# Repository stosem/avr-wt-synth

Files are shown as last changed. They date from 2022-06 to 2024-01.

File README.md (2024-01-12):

# Info

Eurorack Wavetable-based VCO. Atari Glitch. DIY

## Atari Glitch Synthesizer
This is the VCO (voltage controlled oscillator) audio synthesizer module for the Eurorack Modular systems. 
It's based on the Wavetable and FM synthesis using Arduino Mozzi library. 
See the basic circuit diagram in the `cad` folder.

## Interface

We have 4 main potentiometers B100K in order to set Sytentesizer's parameters:
* Wavetable - choose a wavetable 
* Modulation - set modulation depth 
* Obertone - set amount of overtone sound 
* Glitch - FM operator amount 

The same parameters can be set using CV inputs on 3.5mm Jacks. There are several additional CV inputs: 
* Trigger - main gate signal (1-5V) to initiate (trigger) a note 
* 1V/OCT - one volt per octave - the pitch of the note to play 

There is one audio output, also on 3.5mm jack socket: 
* OUT - audio out 

We have also one Switch to choose the Synthesizer mode between two possible modes: 
* Standard FM/Wavetable synth. You can set any parameters using potentiometers or CV signals (higher priority) 
* Random synthesizer. In this mode, all parameters are generated randomly on each step (trigger). Potentiometers now are limiting the maximum possible value of randomly generated values. Set a potentiometer to 0 (zero) if you want to unlimit a random value range. 

## Board
The Synthesizer consists of two boards. 
1. The Interface board, where all potentiometers and 3.5mm jack ports are located
2. The main logic board

All schemes are in the cad directory.

## Demo

Sound demo:

https://www.youtube.com/watch?v=aY03wGdam5E

# User manual

## Switch

* Random On/Off random feature.

If random feature is On, the new sound will be generated at each trigger CV signal

## Knobs

You can switch any knob to 0 value by turning it clockwise till the click.

| Parameter name | Description | Normal mode | Random mode |
| --- | --- | --- | --- |
| WAVE | WaveTable select | Select WaveTable from 0 to max available (MAX\_WT) | Limit Random Wavetable. 0=ALL |
| OBER | Obertone freq | Set Obertone Freq | Limit Obertone Freq. 0=ALL |
| GLITCH | FM intensity | Set FM intensity | Limit FM intensity. 0=ALL |
| MOD | Modulation Rate | Set wah-wah effect | Limit Mod ratio. 0=ALL |

## CVs

CVs have higher priority than knobs

| Parameter name | Description | Normal mode | Random mode |
| --- | --- | --- | --- |
| TRIG | Trigger CV | Make a sound | Generate a random sound |
| V/OCT | Pitch CV | Set pitch (will be quantized to a note) | Set pitch. 0 or no signal = Random pitch |
| GLCH | FM intensity | Set FM intensity | - |
| OBER | Obertone freq | Set obertone freq | - |
| MOD | Modulation Rate | Set wah-wah effect | - |

## Notes

Current range is 5 octaves from C1 to C6

## WaveTables

1. HSN - Half Sinus
2. SIN - Full Sinus
3. SQR - Square
4. SAW - Sawtooth
5. TRI - Triangle

# Developers

## Tips

* Do not use digital pins 11,12,13 if you want to use MOSI/MISO Atmega programmer (especially with capacitors)
* Do not use digital pins 9,10. They are used by Mozzi sound generator
* Change OpIntensityMod WaveTable if you want to get creazy sound
* Use DEBUG\_INPUT to check CVs and knobs. But it's not a good idea to use the Serial messages with Mozzi. Don't forget to undefine debugs.

## Known bugs

* AutoMap doesn't work till it get the maximum value from CV/Knob. It returns always maximum. We can't replace it with map() because it's very slow. Fixed by pushing max value first.
* map() and AutoMap works not so good on the minimum value. For example 0 and 15 - are the same values for it. Therefore C0 and C#0 - are the same notes. Fixed by if-then-hack.

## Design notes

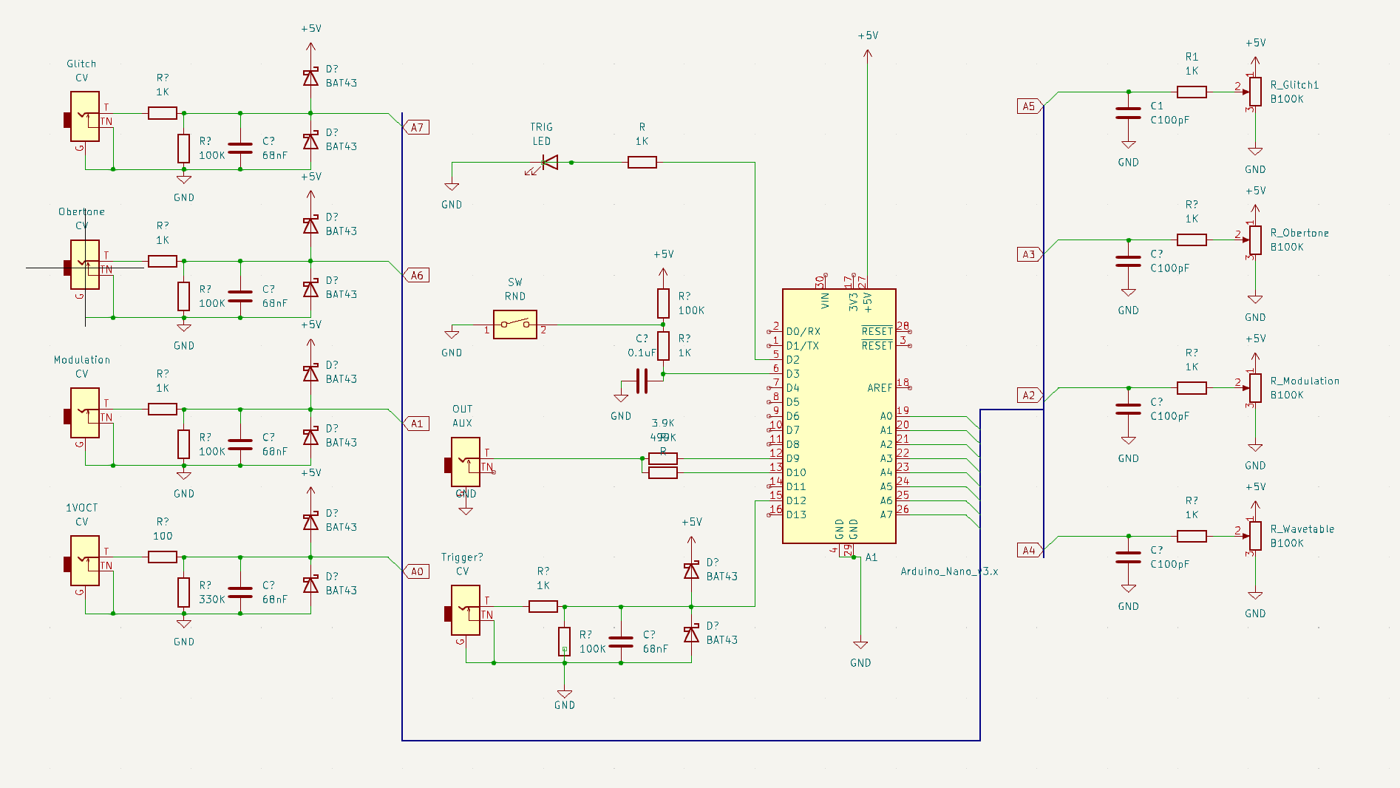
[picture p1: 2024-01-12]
cad/Scheme.png

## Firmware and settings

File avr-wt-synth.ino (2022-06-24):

/*
 * ATARI GLITCH Eurorack module by Alex Bohrium
 * firmware v1.0
 */

#include <MozziGuts.h>
#include <Oscil.h> // oscillator 

#include "tables/halfsin2048_int8.h" // table for Oscils to play
#include <tables/sin2048_int8.h>
#include <tables/square_no_alias_2048_int8.h>
#include <tables/saw2048_int8.h>
#include <tables/triangle2048_int8.h>

#include <Smooth.h>
#include <AutoMap.h> // maps unpredictable inputs to a range

#include <mozzi_rand.h>

/* constants
 *  
 */

// uncomment to debug messages via serial cable
//#define DEBUG_INPUT
//#define DEBUG
#define DEFAULT_BRIGHT     5        // brightness, harmonics
#define DEFAULT_VOL        10       // volume

// constants for mappings
 
// desired carrier frequency (pitch)
#define MIN_CARRIER_FREQ  32.70
#define MAX_CARRIER_FREQ  1046.50
#define DEFAULT_FREQ      220  // if no 1V/Oct signal

// Obertone freq
#define MIN_OBER_FREQ          1
#define MAX_OBER_FREQ          100

// desired intensity max and min, (glitch amount)
#define MAX_INTENSITY     700
#define MIN_INTENSITY     1

// desired mod speed max and min, (fm mod rate)
#define MAX_MOD_SPEED     10000
#define MIN_MOD_SPEED     1

// number of wavetables
#define MAX_WT            5

/* mappings
 *
 */
#define ANALOG_ZERO       10   // minimum treshold to detect a zero/non-zero state (0-1023)

// knobs and CVs maps
AutoMap kMapCarrierFreq( 0, 1023, MIN_CARRIER_FREQ, MAX_CARRIER_FREQ );
AutoMap kMapIntensity( 0, 1023, MIN_INTENSITY, MAX_INTENSITY );
AutoMap kMapModSpeed( 0, 1023, MIN_MOD_SPEED, MAX_MOD_SPEED );
AutoMap kMapOberFreq( 0, 1023, MIN_OBER_FREQ, MAX_OBER_FREQ );
AutoMap kMapWT( 0, 1023, 1, MAX_WT );
// note maps
AutoMap tone_index_map( 0, 1023, 0, 59 );

// notes from C1 to C6
float note_freq[61] = {65.41,   69.30,   73.42,   77.78,   82.41,   87.31,   92.50,   98.00,   103.83,  110.00,  116.54,  123.47,
                       130.81,  138.59,  147.83,  155.56,  164.81,  174.61,  185.00,  196.00,  207.65,  220.00,  233.08,  246.94,
                       261.63,  277.18,  293.66,  311.13,  329.63,  349.23,  369.99,  392.00,  415.30,  440.00,  466.16,  493.88,
                       523.25,  554.37,  587.33,  622.25,  659.25,  698.46,  739.99,  783.99,  830.61,  880.00,  932.33,  987.77,
                       1046.50, 1108.73, 1174.66, 1244.51, 1318.51, 1396.91, 1479.98, 1567.98, 1661.22, 1720.00, 1864.60, 1975.50, 2093.00};

// Hadrware depending configuration
// digital i/o
#define DEBUG_LED   13 // LED for internal debug
#define TRIGGER_LED 2  // Trigger Led will blink when the gate is open
#define RND_SWITCH  3  // Switch RND/Normal
#define TRIGGER_PIN 12 // Sound trigger pin
// analog input
// knobs
#define OBER_KNOB   A3  // Obertone knob
#define MOD_KNOB    A2  // Modulation rate knob
#define WT_KNOB     A4  // Wavetable select knob
#define GLITCH_KNOB A5  // Glitch knob
// CVs
#define MOD_CV      A1  // Modulation rate CV     (wah-wah effect)
#define PITCH_CV    A0  // 1/OCT CV               (base carrier freq / pitch)
#define OBER_CV     A6  // Ober CV                (obertone freq / pitch)
#define GLITCH_CV   A7  // Glitch amount CV       (FM intensity / glitch)


/* variables (may be changed during the work)
 *  
 */

Oscil<2048, AUDIO_RATE>   aOpCarrier;
Oscil<2048, AUDIO_RATE>   aOpModulator;
Oscil<2048, CONTROL_RATE> cOpIntensityMod;

long fm_intensity;                  // carriers control info from updateControl to updateAudio

// smoothing for intensity to remove clicks on transitions
float smoothness = 0.95f;

Smooth <long> aSmoothIntensity(smoothness);

// trigger on flag (change me on trigger button or CV)
bool isTrigger = false;

// regenerate flag
bool isNeedRegenerate = false;

// mode (rnd-generated or manually set)
bool isRND = true;

// define wavetable types
typedef enum WT {
  HSN = 1,
  SIN = 2,
  SQR = 3,
  SAW = 4,
  TRI = 5,
  RND = 6,
} WT;

// define FM-based sound variables
typedef struct tFM {
  int   wt;         // wavetable number
  float carr_freq;  // carrier freq
  int   ober_freq;  // obertone freq
  int   vol;        // volume
  int   fmi;        // FM intensity
  int   bright;     // Brightness (harmonics)
  float mod;   // Modulation rate
} tFM;

// use this function only on debug! it has delay!
void blink_led( int led ) {
      digitalWrite(led, HIGH);
      delay( 100 );
      digitalWrite(led, LOW);
      delay( 100 );
}

// init
void setup(){
#ifdef DEBUG
  Serial.begin(115200); // set up the Serial output
#endif
  // define pins
  pinMode(DEBUG_LED, OUTPUT);
  pinMode(TRIGGER_LED, OUTPUT);
  pinMode(TRIGGER_PIN, INPUT);       // trigger cv
  pinMode(RND_SWITCH, INPUT_PULLUP); // Switch connected to GND    
  blink_led( DEBUG_LED );
  blink_led( TRIGGER_LED );

  randSeed();
  blink_led( DEBUG_LED );
  blink_led( TRIGGER_LED );
  
  startMozzi();
  blink_led( DEBUG_LED );
  blink_led( TRIGGER_LED );
  
#ifdef DEBUG
  Serial.print("Setup finish\n\r");
#endif
}

// update Osc values
void mySetOsc(tFM fmSnd) {
#ifdef DEBUG
  Serial.print("SetOSC:\tWT=");
  Serial.print(fmSnd.wt);
  Serial.print("\tCARR_FREQ=");
  Serial.print(fmSnd.carr_freq);
  Serial.print("\tOBER_FREQ=");
  Serial.print(fmSnd.ober_freq);
  Serial.print("\tVOL=");
  Serial.print(fmSnd.vol);
  Serial.print("\tGLCH=");
  Serial.print(fmSnd.fmi);
  Serial.print("\tBRIGHT=");
  Serial.print(fmSnd.bright);
  Serial.print("\tMOD=");
  Serial.print(fmSnd.mod);
  Serial.print(".\n\r");
#endif
  // set wavetable
  switch ( fmSnd.wt ) {
    case HSN:
      aOpCarrier.setTable(      HALFSIN2048_DATA );
      aOpModulator.setTable(    HALFSIN2048_DATA );
      cOpIntensityMod.setTable( HALFSIN2048_DATA );
    break;
    case SIN:
      aOpCarrier.setTable(      SIN2048_DATA );
      aOpModulator.setTable(    SIN2048_DATA );
      cOpIntensityMod.setTable( SIN2048_DATA );
    break;
    case SQR:
      aOpCarrier.setTable(      SQUARE_NO_ALIAS_2048_DATA );
      aOpModulator.setTable(    SQUARE_NO_ALIAS_2048_DATA );
      cOpIntensityMod.setTable( SIN2048_DATA );
      fmSnd.vol = 5;            // reduce volume for this wave
    break;
    case SAW:
      aOpCarrier.setTable(      SAW2048_DATA );
      aOpModulator.setTable(    SAW2048_DATA );
      cOpIntensityMod.setTable( SIN2048_DATA );
    break;
    case TRI:
      aOpCarrier.setTable(      TRIANGLE2048_DATA );
      aOpModulator.setTable(    TRIANGLE2048_DATA );
      cOpIntensityMod.setTable( SIN2048_DATA );
    break;
  }
  //calculate the modulation frequency to stay in ratio
  int mod_freq = fmSnd.carr_freq * fmSnd.ober_freq * fmSnd.bright;
  // calculate the fm_intensity
  fm_intensity = ((long)fmSnd.fmi * fmSnd.vol * (cOpIntensityMod.next()+128))>>8; // shift back to range after 8 bit multiply
  // set the FM oscillator frequencies
  aOpCarrier.setFreq( fmSnd.carr_freq ); 
  aOpModulator.setFreq( mod_freq );
  cOpIntensityMod.setFreq( fmSnd.mod );
}


// Mozzi Update Controls
void updateControl(){

  // digital read
  isTrigger = (digitalRead( TRIGGER_PIN ) == HIGH)?true:false; // trigger pin connected to an external +5V signal
  isRND = (digitalRead( RND_SWITCH ) == LOW)?true:false;       // rnd switch connected to the GND

#ifdef DEBUG_INPUT
  Serial.print("UpdateControl.Read:\tisTrigger=");
  Serial.print(isTrigger);
  Serial.print("\tisRND=");
  Serial.print(isRND);
  Serial.print("\n\r");
#endif
  
  // set trigger led
  if ( isTrigger ) {
    digitalWrite(TRIGGER_LED, HIGH);
  } else {
    digitalWrite(TRIGGER_LED, LOW);
    // need regenerate on the next trigger comming
    if ( isRND && !isNeedRegenerate ) { 
      isNeedRegenerate = true ;
    };
    // we don't want do anything without a trigger
    return;
  }
  
  // analog read
  // knobs
  int wtKnobVal   = mozziAnalogRead( WT_KNOB );      // read wavetable knob        value is 0-1023
  int modKnobVal  = mozziAnalogRead( MOD_KNOB );     // read modulation rate knob  value is 0-1023
  int oberKnobVal = mozziAnalogRead( OBER_KNOB );    // read obertone knob         value is 0-1023
  int fmiKnobVal  = mozziAnalogRead( GLITCH_KNOB );  // read glitch knob           value is 0-1023
  // CVs
  int carrCVVal   = mozziAnalogRead( PITCH_CV );     // read 1V/OCT pitch          value is 0-1023
  int modCVVal    = mozziAnalogRead( MOD_CV );       // read modulation rate CV    value is 0-1023
  int oberCVVal   = mozziAnalogRead( OBER_CV );      // read obertone CV           value is 0-1023
  int fmiCVVal    = mozziAnalogRead( GLITCH_CV );    // read glitch CV             value is 0-1023

  tFM fmSnd; // sound configuration instance
  // AutoMap has an issue: it return wrong value till it doesn't recive the maximum.
  fmSnd.wt=kMapWT( 1023 );
  fmSnd.carr_freq=kMapCarrierFreq( 1023 );
  fmSnd.ober_freq=kMapOberFreq( 1023 );
  fmSnd.vol=DEFAULT_VOL;
  fmSnd.fmi=kMapIntensity( 1023 );
  fmSnd.bright=DEFAULT_BRIGHT;
  fmSnd.mod=kMapModSpeed( 1023 );
  byte noteNum=tone_index_map( 1023 );
      
#ifdef DEBUG_INPUT
  Serial.print("\tWTknob=");
  Serial.print(wtKnobVal);
  Serial.print("\tMODknob=");
  Serial.print(modKnobVal);
  Serial.print("\toOBERknob=");
  Serial.print(oberKnobVal);
  Serial.print("\tGLCHknob=");
  Serial.print(fmiKnobVal);
  Serial.print("\tCARRcv=");
  Serial.print(carrCVVal);
  Serial.print("\tMODcv=");
  Serial.print(modCVVal);
  Serial.print("\tOBERcv=");
  Serial.print(oberCVVal);
  Serial.print("\tGLCHcv=");
  Serial.print(fmiCVVal);
  Serial.print(".\n\r");
#endif

  if ( isRND ) {
  // this is RANDOM mode
    // do we need to generate a new sound? (only on a new trigger)
    if ( isNeedRegenerate ) {
       // set WT limited by WT Knob (if > 0)
       int iMaxWT        = ( wtKnobVal > ANALOG_ZERO )?kMapWT( wtKnobVal ):MAX_WT;  // limit WT range by WT knob (if > 0)
       fmSnd.wt          = rand((int)1,(int)iMaxWT+1);
       // set pitch = CV if it's exists, or RND if no 1V/OCT signal
       fmSnd.carr_freq   = ( carrCVVal > ANALOG_ZERO )?kMapCarrierFreq( carrCVVal ):rand((int)MIN_CARRIER_FREQ,(int)MAX_CARRIER_FREQ+1); // starting not from minimum to skip sub freq
       // set obertone
       int iMaxOber      = ( oberKnobVal > ANALOG_ZERO )?kMapOberFreq( oberKnobVal ):MAX_OBER_FREQ; // limit Obertone Freq by Ober Knob (if > 0)
       fmSnd.ober_freq   = rand((int)MIN_OBER_FREQ,(int)iMaxOber+1);
       // set volume
       fmSnd.vol         = DEFAULT_VOL;
       // set glitch
       int iMaxIntensity = ( fmiKnobVal > ANALOG_ZERO )?kMapIntensity( fmiKnobVal ):MAX_INTENSITY; // limit intensity by Glitch Knob (if > 0)
       fmSnd.fmi         = rand((int)MIN_INTENSITY,(int)iMaxIntensity+1);
       // set modulation rate
       int iMaxMod       = ( modKnobVal > ANALOG_ZERO )?kMapModSpeed( modKnobVal ):MAX_MOD_SPEED; // limit intensity by Glitch Knob (if > 0)
       if ( iMaxMod < MIN_MOD_SPEED ) { iMaxMod = MIN_MOD_SPEED; };
       fmSnd.mod         = (float)rand((int)MIN_MOD_SPEED,(int)iMaxMod-MIN_MOD_SPEED+1)/1000;
       // set brightness
       fmSnd.bright      = DEFAULT_BRIGHT; // rand((int)1,(int)32);
       mySetOsc( fmSnd );
       // regeniration is done
       isNeedRegenerate = false;

#ifdef DEBUG
  Serial.print("UpdateControl.RNDGen:\tCARR_FREQ=");
  Serial.print(fmSnd.carr_freq);
  Serial.print("\tlimitWT=");
  Serial.print(iMaxWT);
  Serial.print("\tlimitOBER=");
  Serial.print(iMaxOber);
  Serial.print("\tlimitCLCH=");
  Serial.print(iMaxIntensity);
  Serial.print("\tlimitMOD=");
  Serial.print(iMaxMod);
  Serial.print(".\n\r");
#endif
    }
    return; // end of RND mode
      
  } else {
  // this is NORMAL mode

    // define FM
    fmSnd.wt = kMapWT( wtKnobVal );
    fmSnd.vol = DEFAULT_VOL; // constant volume
    // set pitch
    // fmSnd.carr_freq = kMapCarrierFreq( carrCVVal ); // raw freq mapping
    noteNum = tone_index_map( carrCVVal )+1;
    // hack: map() detect 0 and 15 as the same value. It returns 0.
    if ( carrCVVal <= 10 ) { noteNum = 0; };
    if (( carrCVVal > 10 ) && ( carrCVVal < 30 )) { noteNum = 1; };
    fmSnd.carr_freq = (float)note_freq[ noteNum ]; // quantized notes
#ifdef DEBUG
  Serial.print("\tnoteNum=");
  Serial.print(noteNum);
  Serial.print(".\n\r");
#endif
    // set obertone freq
    fmSnd.ober_freq = ( oberCVVal > ANALOG_ZERO )?kMapOberFreq( oberCVVal ):kMapOberFreq( oberKnobVal );
    // set FM intensity (glitch)
    fmSnd.fmi       = ( fmiCVVal > ANALOG_ZERO )?kMapIntensity( fmiCVVal ):kMapIntensity( fmiKnobVal );
    // set modulation rate
    fmSnd.mod       = ( modCVVal > ANALOG_ZERO )?(float)kMapModSpeed( modCVVal )/1000:(float)kMapModSpeed( modKnobVal )/1000;
    fmSnd.bright    = DEFAULT_BRIGHT;
    // set resutl
    mySetOsc( fmSnd );
    return; // end of NORMAL mode
  }
  

}


int updateAudio(){
  // silence when not triggered
  if ( ! isTrigger ) { return ; }
  
  long modulation = aOpModulator.next() * aSmoothIntensity.next(fm_intensity) ;
  return aOpCarrier.phMod(modulation);
}


void loop(){
  audioHook();
}

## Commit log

2022-06-24 init import
    [m3-board-interface-traced1.kicad_pcb, m3-board-main-traced1.kicad_pcb, m3.kicad_sch]
2024-01-12 add circuit diagram
